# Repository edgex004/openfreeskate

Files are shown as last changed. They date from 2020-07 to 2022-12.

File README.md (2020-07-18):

# openfreeskate
Open source design for 3D printed driftskate/freeskate

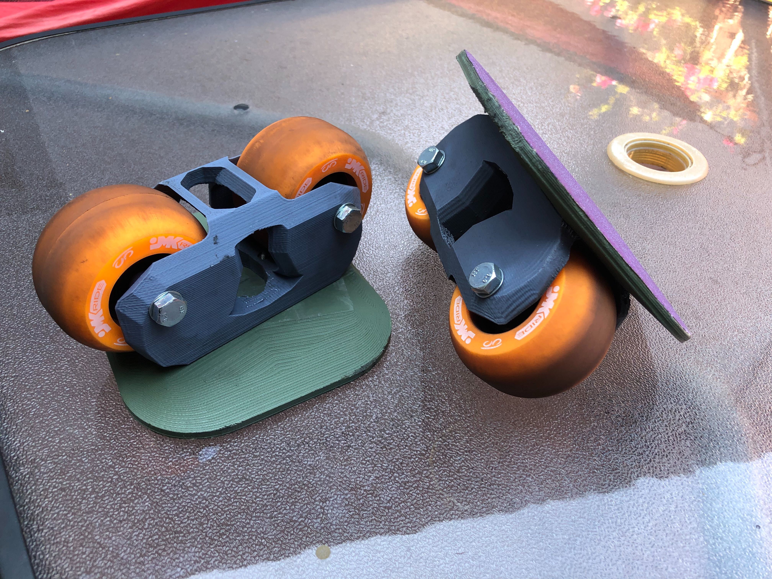
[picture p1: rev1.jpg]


### Design 
The skates are made up of three top-level modules that you need to print:
* 2 Decks
* 2 Trucks
* 4 Bearing spacers

### Additional parts required for build:
* 4 M4x15mm bolts (or cut down longer M4's)
* 4 M4 nuts
* 4 M8x80mm partially threaded bolts
* 4 M8 locking nuts

### Note
The bottom of the M8 bolts can just barely strike the ground when the skates are tipped over. This can be avoided by either cutting the bolts short or by adding M8 washers near the head of the bolt. You can probably also use M8x70mm bolts instead of cutting, but that will leave threading underneath the bearing spacers.
 
The width of the bearing spacers needs to be adjusted to fit your choice of wheels/bearings.

The default design is compatible with JMKRide Performance Wheels/Bearings. ( ```bearing_to_bearing=26.5;```)

I do not own any other sets of trucks or decks, so I am assuming this design is not compatible with any existing products on the market. If anyone wants to request specific bolt sizes or hole spacing for compatibility reasons, simply send me the requested dimensions and I can implement them in the next revision.

### Disclaimer

I use these skates personally. However, I cannot vouch for the safety or validity of this design. Anyone who chooses to use this design does so at their own risk. The printer/user should perform their own due diligence, materials choice, and testing prior to riding on these skates.

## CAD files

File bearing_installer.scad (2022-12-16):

$fn=50;

bolt_diameter=12;
bearing_diameter=22;

difference(){
    circle(r=(bearing_diameter+4)/2);

    circle(r=bolt_diameter/2);
}

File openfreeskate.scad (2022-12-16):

// Check this option to rotate the parts for optimal print orientation. Some parts cannot be printed as a signle part.
rotateForPrint = false;
// Lower quality gives faster compile times and a more polygonal shape. Higher qualit adds more smoothly rounded wheel wells.
qualitySelection = 25;  // [1:100]
// Trucks/Decks in general are compatible with any brand. Bearing adaptors and wheels change size with brand.
wheelBrand = "JMKPerformance"; // [JMKPerformance, TwoLions]
deckBoltSize = "M5"; // [None, M4, M5]
// Using the "light" option hollows out the interior of the truck. Using this option will use less filament, but only if your printer can print the midsection wihout supports.
light = true;
// Using the "simple" option aims to have faster rendering, but may be missing some interesting curves.
simple = true;
// Mirror the parts in the direction of the y axis
mirrorParts = false;
// Wheel diameter affects both the trucks and the wheels. If you bump your wheel diameter up to the max, the trucks will adjust to fit the wheels.
Wheel_Diameter = 73; // [65:90]
// Increase or decrease the axle to axle distance of the truck. With the default settings, the total distance comes to about 99mm (compare to 103mm on JMK). Axle to axle distance is calculated as : Wheel_Diameter + Added_Axle_Distance + Gap (so wheels never hit each other even with Added_Axle_Distance of 0)
Added_Axle_Distance = 20; // [0:40]

/* [Wheel] */
showWheel = false;
wheel_type = "OnePiece"; // [OnePiece, TwoPiece_hub, TwoPiece_tire]
// Only affects two-piece wheels. Gap between hub and tire (in 1/10 mm).
tireHubGap = 0; // [0:20]
// Only affects two-piece wheels. Hub size (in mm).
hubDiameter = 40; // [30:60]
// Only affects two-piece wheels. Depth of the lip that holds the tire on (in 1/10 mm).
hubLipDepth = 30; // [0:100]
// Only affects two-piece wheels. Wdth of the lip that holds the tire on (in 1/10 mm).
hubLipBase = 70; // [0:200]
// Only affects two-piece wheels. Wdth of the lip that holds the tire on (in 1/10 mm).
hubLipTip = 30; // [0:200]
// Only affects two-piece wheels. Wdth of the lip that holds the tire on (in 1/10 mm).
numHubLips = 2; // [0:4]
// Controls how much extra space there is between the hub lips and the edge of the hub.
hubEdgePercent = 150; // [0:200]

/* [Deck] */
showPrintedDeck = false;
showLaserDeck = false;
// Laser cut deck only. Select which layer to cut.
laserDeckLayer = "Bottom"; // [Bottom, Middle, Top]
laserTopScale = 100; // [0:100]
laserMiddleScale = 95; // [0:100]
laserBottomScale = 85; // [0:100]
wood_thickness=3.0;

Deck_Width=140; // [50:200]
Deck_Height=165; // [50:200]
Toe_Heel_Edge_Radius=40; // [1:100]
Sides_Edge_Radius=40; // [1:100]
Added_Arch_Bump_Width=0; // [-20:20]
Added_Arch_Bump_Height=0; // [-20:20]
/* [Truck] */
showTruck = false;
/* [Axles] */
axle_bolt_flathead=true;
showAxleBolts = false;
showAxleNuts = false;

/* [Bearing Adaptor] */
showBearingAdaptor = false;
bearingAdaptorTightness = "M8Shaft"; // [M8Shaft, M8Threads]

/* [Metal Parts] */
show_deck_bolts = false;


module print_build(){
    rotate([0,-90,0]) {
        if (showTruck)
            if(simple)
                simpler_lightweight_truck();
            else
                truck(light);
        if (showPrintedDeck)
            deck(make_bolt_cuts);
    }
    if (showBearingAdaptor)
        bearing_adaptor();
    if (showLaserDeck)
        if(laserDeckLayer=="Bottom")
            LazerDeckBottom();
        else if (laserDeckLayer=="Middle")
            LazerDeckMiddle();
        else if (laserDeckLayer=="Top")
            LazerDeckTop();
    if (showWheel){
        if(wheel_type=="OnePiece")
            one_piece_wheel();
        else if (wheel_type=="TwoPiece_hub")
            wheel_hub();
        else if (wheel_type=="TwoPiece_tire")
            wheel_tire();
    }
}

module assembled_build(target){
    if (showAxleBolts)
        move_to_well_locations()
        axle_bolt();
    if (showAxleNuts)
        move_to_well_locations(no_part_flip=true)
        axle_nut();
    if (showTruck)
        if(simple)
            simpler_lightweight_truck();
        else
            truck(light);
    if (showPrintedDeck)
        deck(true);
    if (showBearingAdaptor)
        bearing_adaptor();
    if (showLaserDeck)
    MoveDeckFromCenterToTruck() 
        2dto3d() {
                                    LazerDeckTop();
            LazerDeckMiddle();

                        LazerDeckBottom();


        }
    if (show_deck_bolts)
        four_deckbolts();
    if (showWheel)
        move_to_well_locations() translate([0,0,wheel_gap])
            if(wheel_type=="OnePiece")
                one_piece_wheel();
            else if (wheel_type=="TwoPiece_hub")
                wheel_hub();
            else if (wheel_type=="TwoPiece_tire")
                wheel_tire();
}

function btoi(input) = input ? 1 : 0;
multipe_parts = (btoi(showPrintedDeck) + btoi(showLaserDeck) + btoi(showTruck) + btoi(showWheel) + btoi(showBearingAdaptor)) > 1;
deck_and_truck_only = !(showLaserDeck || showWheel || showBearingAdaptor);
can_print = !rotateForPrint || ( deck_and_truck_only || !multipe_parts);

assert(can_print, "Only the truck + deck may be printed together as a single part.");

if (showPrintedDeck||showLaserDeck) {
    assert((Toe_Heel_Edge_Radius < Deck_Width / 2), "Toe Edge radius for deck must be less than half the width.");
    assert((Sides_Edge_Radius < Deck_Height / 2), "Side Edge radius for deck must be less than half the height.");
}


if (rotateForPrint)
    if (mirrorParts)
        mirror([0,1,0])
            print_build();
    else
        print_build();

else
    if (mirrorParts)
        mirror([0,1,0])
            assembled_build();
    else
        assembled_build();
 
 
 $quality = qualitySelection/100; // Quality scale 0 to 1. 1 Takes a lot of CPU/RAM to render for now.
   $fa =  1/ $quality;
$fs = 1 / $quality;
 //$fn = round(100*$quality);
    //wheel info here
    od=Wheel_Diameter;
    id=20;
    edge_r=25;
    edge_r_offset=8;
    w=43;
    bearing_to_bearing = ( wheelBrand == "JMKPerformance" ) ? 26.5 : 24.5; // Change this to 26.5 for JMK Performance wheels. Twolions seem to be 24.5.
    tireHubGap_mm = tireHubGap / 10.0;
    hubLipDepth_mm = hubLipDepth / 10.0;
    // hubLipWidth_mm = hubLipWidth / 10.0;
    hubLipBase_mm = hubLipBase / 10.0;
    hubLipTip_mm = hubLipTip / 10.0;
    hubEdgeRatio = hubEdgePercent /100.0;
    wheel_overhang = (w-bearing_to_bearing)/2;

    //non-wheel
    bolt_head_radius=8;
    wall_thickness=16;
    bolt_wall_thickness=8;
    wall_slope_height=30;
    wheel_gap=3;
    whell_shell_width=10;
    added_wheel_distance=Added_Axle_Distance;
    wheel_coverage_ratio=.9;
    wheel_coverage_offset=(od/pow(wheel_coverage_ratio,1.55))/8;
    truck_height=wheel_coverage_ratio*od;
   
   wheel_hull_shrink_ratio=.8;
   
    axle_bolt_thread_diameter=8.4;
    axle_bolt_length=70;
    axle_bolt_head_height=4;
    // Flathead bolts have 90 degree angle to the head, so: outer_radius = inner_radius + head_height
    axle_bolt_head_diameter=axle_bolt_flathead? 2 * (axle_bolt_thread_diameter/2 + axle_bolt_head_height) : bolt_head_radius*2;

    axle_nut_thread_id=axle_bolt_thread_diameter;
    axle_nut_thread_od=9.3;
    axle_nut_length=axle_bolt_flathead? 8.5 : axle_bolt_head_height;
    axle_nut_head_height=axle_bolt_flathead? 1 : axle_bolt_head_height;
    axle_nut_head_diameter=axle_bolt_flathead? 20 : bolt_head_radius*2;
    axle_nut_tooth_length = 7.5;
    axle_nut_tooth_width = 5;


    bearing_shell_od=22;
    bearing_shell_id=axle_bolt_thread_diameter;
    bearing_shell_w=8;
    
    deck_bolt_size = deckBoltSize; // M4 vs M5 for now.

    use_m4 = deck_bolt_size == "M4";
    use_m5 = deck_bolt_size == "M5";
    make_bolt_cuts = use_m4 || use_m5;

    // assert(use_m4 || use_m5);



    deck_bolt_head_bore_h = use_m4 ? 4 : use_m5 ? 5 : 5;
    deck_bolt_head_bore_r= use_m4 ? 3.5 : use_m5 ? 4.3 : 4.3;
    deck_bolt_total_h= use_m4 ? 19.7 : use_m5 ? 20.8 : 20.8;
    deck_bolt_total_r= use_m4 ? 2 : use_m5 ? 2.5 : 2.5;
    deck_bolt_nut_bore_r= use_m4 ? 4 : use_m5 ? 4.6 : 4.6;
    deck_bolt_nut_bore_h= use_m4 ? 3 : use_m5 ? 3.8 : 3.8;

    deck_bolt_nut_bore_translation=deck_bolt_head_bore_h+10;
    deck_bolt_nut_bore_hull_translation=[10,0,10];


    deck_bolt_nut_bore_extra_h=deck_bolt_nut_bore_h*1.1; //actual h is 3 or 3.8, but this is to go through the whole truck
    deck_angle=14;
    deck_edge_r_x=Sides_Edge_Radius;
    deck_edge_r_y=Toe_Heel_Edge_Radius;
    deck_thickness_edge=5;
    deck_thickness=deck_bolt_head_bore_h+5;

    bolt_distance=42;
    bolt_distance_from_center=bolt_distance/2; // JMK bolt distance is 63.7/2 based off https://www.thingiverse.com/thing:4152124.
    // 4 bolt measurements from https://www.thingiverse.com/thing:4152124. bolt distance is 51/2. distance in the horizontal is 78.2 total.
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

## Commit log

2020-07-18 Rev 1.
    [openfreeskate.scad]
2020-07-20 Update to tighten the M8 holes slightly and to give the stl files a better default print orientation.
    [openfreeskate.scad]
2020-08-12 Start work on V2.
    [openfreeskate.scad]
2020-09-25 Cleanup code a LITTLE bit. Add customizer.
    [openfreeskate.scad]
2020-10-03 Major overhaul to customizer. Add tabs. Add ability to render parts as an assembly. Add ability to render deck and truck as one piece without bolts. Add Wheel customizer.
    [openfreeskate.scad]
2020-10-03 Add more customizations to the hub and chage the shape of the lips that hold the tire to the hub.
    [openfreeskate.scad]
2020-10-04 Fix 2 manifold warning for tire.
    [openfreeskate.scad]
2020-10-08 Add the ability to add horzontal bumpouts to the deck.
    [openfreeskate.scad]
2022-06-06 Almost done with a new revision. Need to thicken one thin wall
    [openfreeskate.scad]
2022-06-06 Getting close to rev4 I think.
    [openfreeskate.scad]
2022-12-16 Checkpoint commit.
    [bearing_installer.scad, openfreeskate.scad]
